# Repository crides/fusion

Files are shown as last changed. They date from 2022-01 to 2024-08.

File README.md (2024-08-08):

# Fusion

My travel board. Uses minimum spacing with choc mini (PG1232) and Cirque touchpad. It's meant to be folded for easy packing for traveling/going to classes. It's called fusion because the halves are now "fused" together (all my previous boards have been split).

The following picture shows how it's originally assembled:

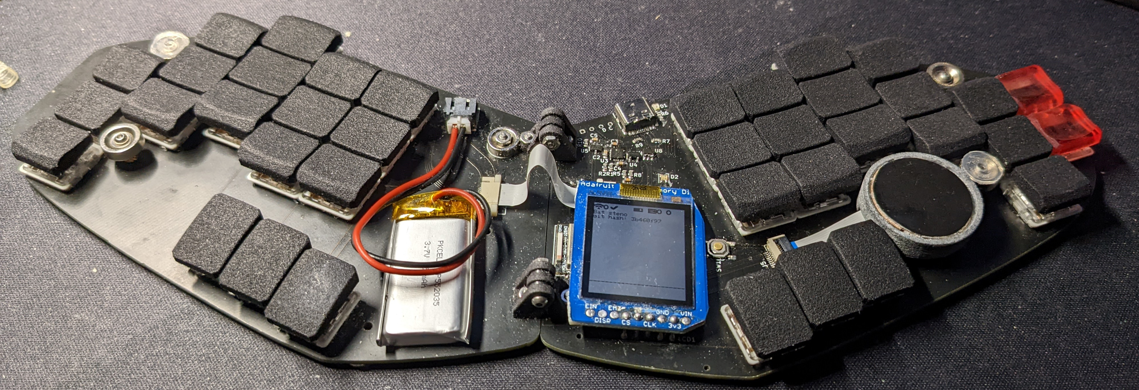
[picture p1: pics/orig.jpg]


You can find the caps [here](https://github.com/crides/sqdg). They are printed with the MJF Nylon process at JLCPCB.

The 2 extra pinky keys on the right side are different because I forgot about them when designing and printing the keycaps. Those keys are for steno, and like [the `fissure`](https://github.com/crides/fissure/) this includes [embedded stenograpy](https://github.com/crides/steno/).

The keymap is basically the same as [on the fissure](https://github.com/crides/fissure/?tab=readme-ov-file#latest-keymap) with a little difference in how the gaming and alternative layout layers are toggled.

One extra small feature it has is a PWM controlled RGB LED, which I use to display [LED widgets](https://github.com/zmkfirmware/zmk/issues/1003) on.

You can find a recent-ish configuration for this board [here](https://github.com/crides/zmk/tree/fusion-led-c-config/).

With the 350mAh battery on the board, this lasted me ~5 months of usage (it could've been even longer, the battery started out not on full charge (~3.8V)).

The board measures 148 x 79.5 x 21mm when it's folded (23mm thick if you include the bumpons, and 133mm long if the last 2 keys are cut off, like in the current state (see the bottom of this page)), which fits into a small bag. I carry this with my Pixel 5a in my big sweatpants pocket for quite a while. I would just go to places, take out the keeb and my phone, unfold it and work with Termux.

All parts are generated from Python, some using [solidff](https://github.com/crides/solidff), some using [CadQuery](https://github.com/CadQuery/cadquery/), depending on when the part was designed. The only parts actually used are `hinge1`, `hinge2` and `touchpad-holder`.

Includes JLCPCB BOM ([`bom.csv`](bom.csv)) and POS ([`pos.csv`](pos.csv)) files for PCBA.

---

Here's the board after almost 11 months of usage (right before 2023):

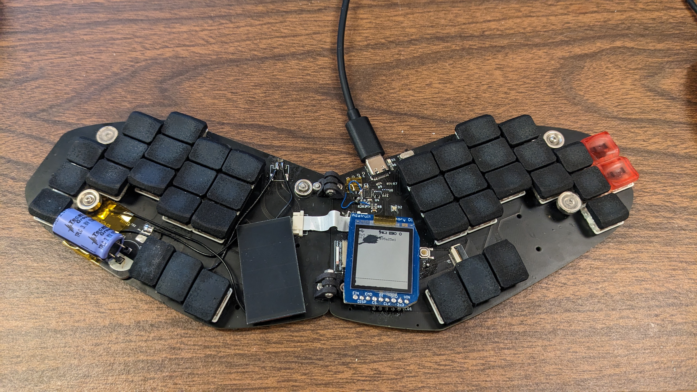
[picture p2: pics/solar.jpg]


Main differences:
- The trackpad is in a really weird spot. I knew this in the design phase, but didn't have much idea of how to fix it. So it's taken out. 
- A solar charging circuit with a Li-ion supercapacitor is added, replacing the battery and its charging circuit. The current supercap is 150F (!), which is equivalent to about 40mAh. This was to be done on another version of the board, but a small test circuit was fabbed instead, and that was used here with a fair amount of bodging. Now I can say the fusion board is (well can be) powered by fusion! (a.k.a. solar powered)
- There's a crack on the screen. The adhesive I used didn't cover the whole screen area, and once I pressed on the top left corner too hard, where the adhesive also didn't cover and left some empty space, and it cracked :(.

---

Here it is after 1 year:

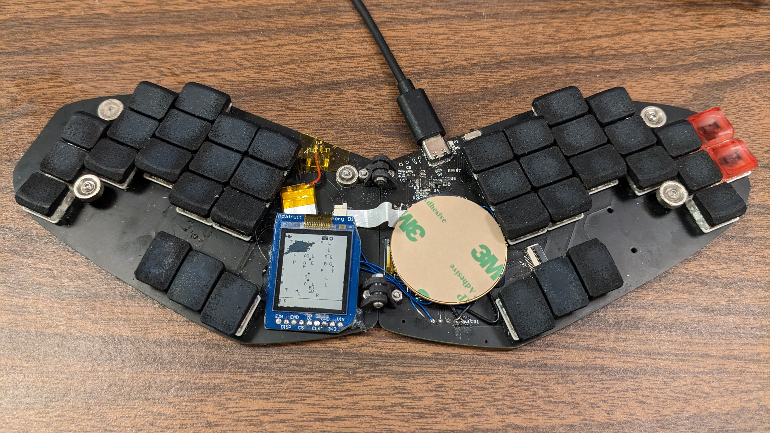
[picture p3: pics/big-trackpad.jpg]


Somehow the supercap doesn't seem to do well with the cold, so I swapped to the old small battery. Tried out a larger Cirque touchpad, by basically shifting the screen to the left side though a bunch of wires.

---

Here's what it looks like after 16 months:

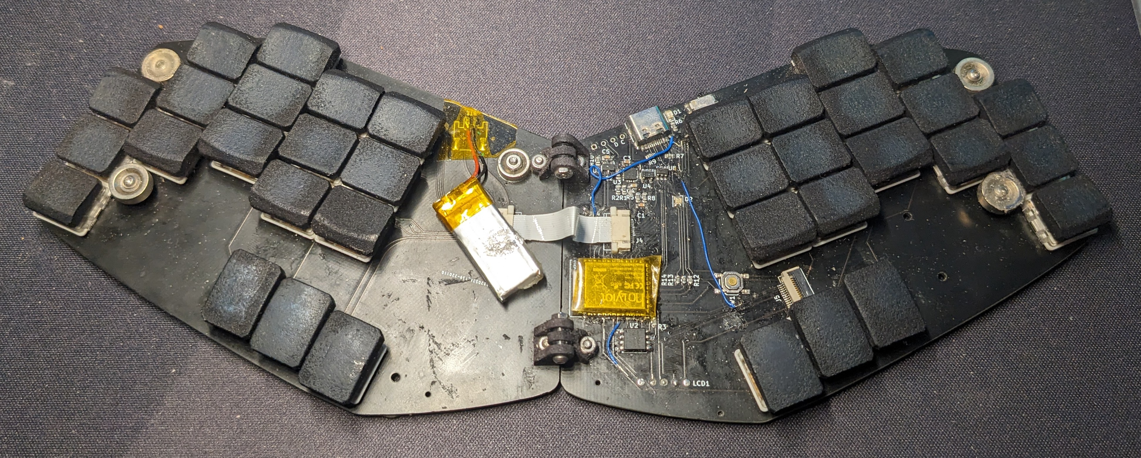
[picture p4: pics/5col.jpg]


The screen's completely broken, with the ribbon cable half "cut" (no idea how that happened). The trackpad location is better, but still pretty useless for my use cases (I use it 95% on top of my laptop keyboard most of the time, and the touchpad is right there, with more ready-to-be-used gestures. So touchpads and solar panels are gone. Nothing interesting to see here...

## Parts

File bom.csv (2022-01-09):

Comment | Designator | Footprint | LCSC
Battery_Cell | BT1 | Connector_JST:JST_PH_S2B-PH-SM4-TB_1x02-1MP_P2.00mm_Horizontal
10nF | C1 | Capacitor_SMD:C_0603_1608Metric
4.7uF | C2,C3,C4 | Capacitor_SMD:C_0603_1608Metric
0.1uF | C5 | Capacitor_SMD:C_0603_1608Metric | C14663
RED | D1 | LED_SMD:LED_0805_2012Metric
LED_RABG | D2 | LED_SMD:LED_ASMB-KTF0-0A306 | C375569
bat-shell | H20 | fusion:bat-shell-small
USB_C_Receptacle_USB2.0 | J2 | Connector_USB:USB_C_Receptacle_HRO_TYPE-C-31-M-12 | C165948
cirque-trackpad | J5 | Connector_FFC-FPC:Hirose_FH12-12S-0.5SH_1x12-1MP_P0.50mm_Horizontal
diode-choc | K1,K6,K11,K19,K24,K29,K34,K35 | pg1232:pg1232-DSSN | C64898
diode-choc | K2,K5,K7,K10,K12,K15,K22,K27,K32 | pg1232:pg1232-DSSR | C64898
diode-choc | K3,K8,K13,K16,K17,K18,K21,K26,K31,K36,K37,K38 | pg1232:pg1232-DSS | C64898
diode-choc | K4,K9,K14,K20,K23,K25,K28,K30,K33 | pg1232:pg1232-DSSL | C64898
adafruit-sharp-memory-display-no-useless | LCD1 | display:adafruit-sharp-memory-display-1.3in-no-mounting-no-useless
10k | R1,R2 | Resistor_SMD:R_0603_1608Metric
100k | R3,R10 | Resistor_SMD:R_0603_1608Metric
5.1M | R5,R8 | Resistor_SMD:R_0603_1608Metric | C13320
1k | R6,R14 | Resistor_SMD:R_0603_1608Metric
5.1k | R7,R9 | Resistor_SMD:R_0603_1608Metric
1.2k | R12 | Resistor_SMD:R_0603_1608Metric
1.5k | R13 | Resistor_SMD:R_0603_1608Metric
SW_Push | SW1 | Button_Switch_SMD:SW_SPST_TL3342 | C318884
SW_SPDT | SW2 | Button_Switch_SMD:SW_SPDT_PCM12 | C431541
holyiot-18010-no-underside | U1 | mcu:holyiot-18010-no-underside
MT25QL128ABA1ESE | U2 | Package_SO:SOIC-8_5.23x5.23mm_P1.27mm | C97521
BQ24075 | U3 | Package_DFN_QFN:VQFN-16-1EP_3x3mm_P0.5mm_EP1.68x1.68mm_ThermalVias
XC6206B331MR | U4 | Package_TO_SOT_SMD:SOT-23-5 | C155728
LN4913 | U5 | Package_TO_SOT_SMD:SOT-23 | C236384
SRV05-4 | U8 | Package_TO_SOT_SMD:SOT-23-6

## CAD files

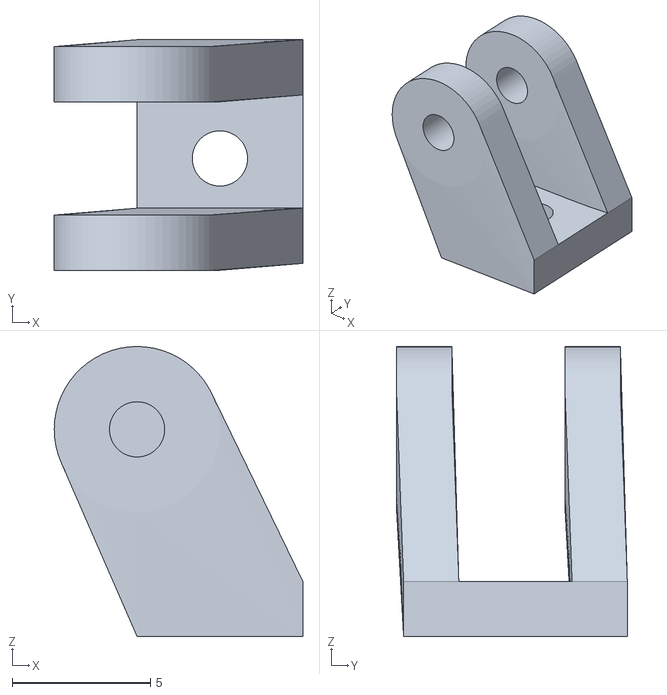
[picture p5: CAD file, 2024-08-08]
hinge2.stl
9.00 x 8.35 x 10.5

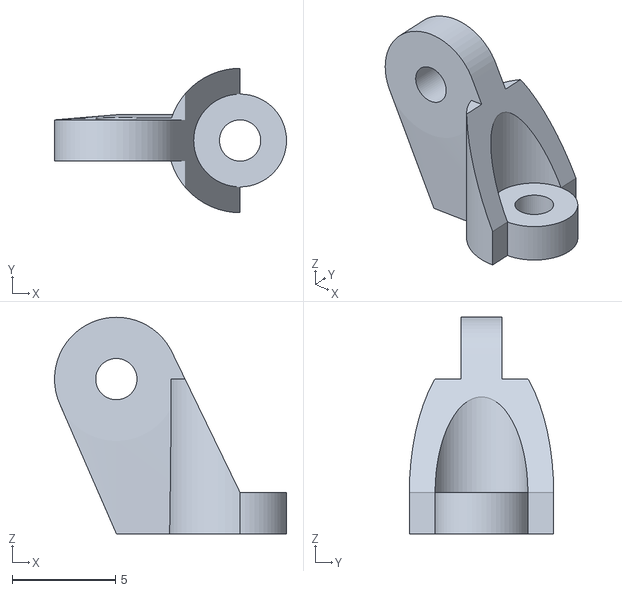
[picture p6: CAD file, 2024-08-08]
hinge1.stl
11.2 x 7.00 x 10.5

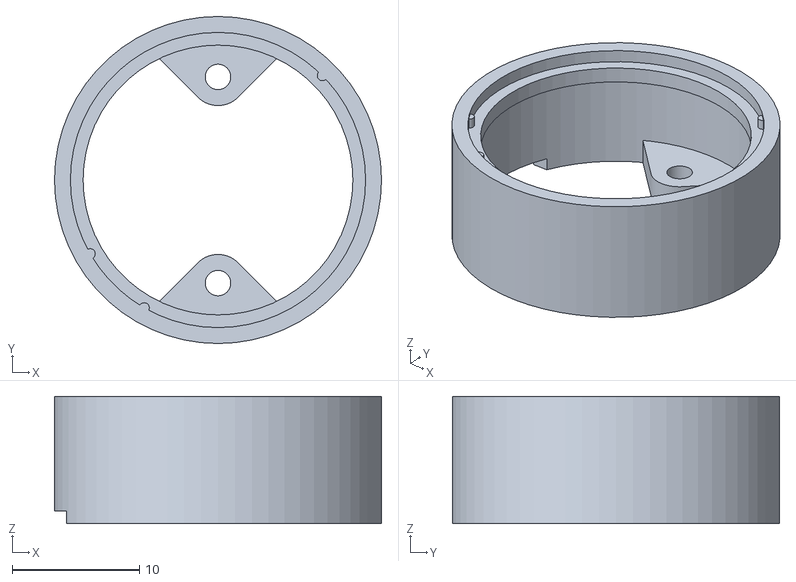
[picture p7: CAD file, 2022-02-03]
touchpad-holder.stl
25.7 x 25.7 x 10.0

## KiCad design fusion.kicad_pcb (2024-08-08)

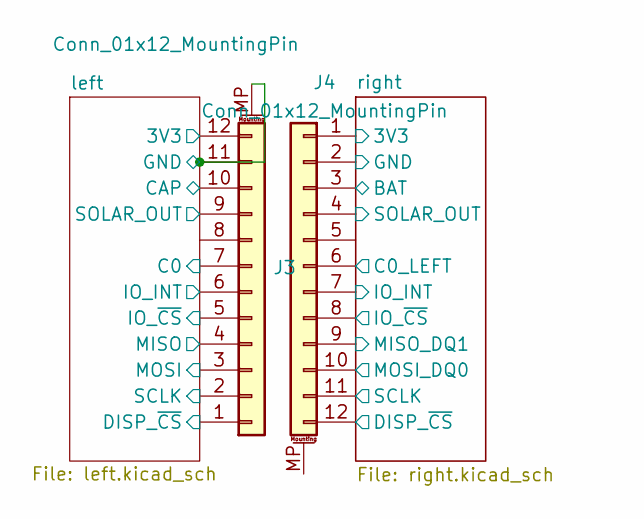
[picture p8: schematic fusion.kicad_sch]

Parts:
J3, J4: Conn_01x12_MountingPin; Hirose_FH12-12S-0.5SH_1x12-1MP_P0.50mm_Horizontal

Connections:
/left/3V3: J3.12; also elsewhere on the board
/left/C0: J3.7; also elsewhere on the board
/left/CAP: J3.10; also elsewhere on the board
/left/DISP_~CS: J3.1; also elsewhere on the board
/left/GND: J3.11, J3.MP (MountPin); also elsewhere on the board
/left/IO_INT: J3.6; also elsewhere on the board
/left/IO_~CS: J3.5; also elsewhere on the board
/left/MISO: J3.4; also elsewhere on the board
/left/MOSI: J3.3; also elsewhere on the board
/left/SCLK: J3.2; also elsewhere on the board
/left/SOLAR_OUT: J3.9; also elsewhere on the board
/right/3V3_nRF: J4.1; also elsewhere on the board
/right/BAT: J4.3; also elsewhere on the board
/right/C0_LEFT: J4.6; also elsewhere on the board
/right/DISP_~CS: J4.12; also elsewhere on the board
/right/IO_INT: J4.7; also elsewhere on the board
/right/IO_~CS: J4.8; also elsewhere on the board
/right/MISO_DQ1: J4.9; also elsewhere on the board
/right/MOSI_DQ0: J4.10; also elsewhere on the board
/right/SCLK: J4.11; also elsewhere on the board
/right/SOLAR_OUT: J4.4; also elsewhere on the board
GND: J4.2; also elsewhere on the board

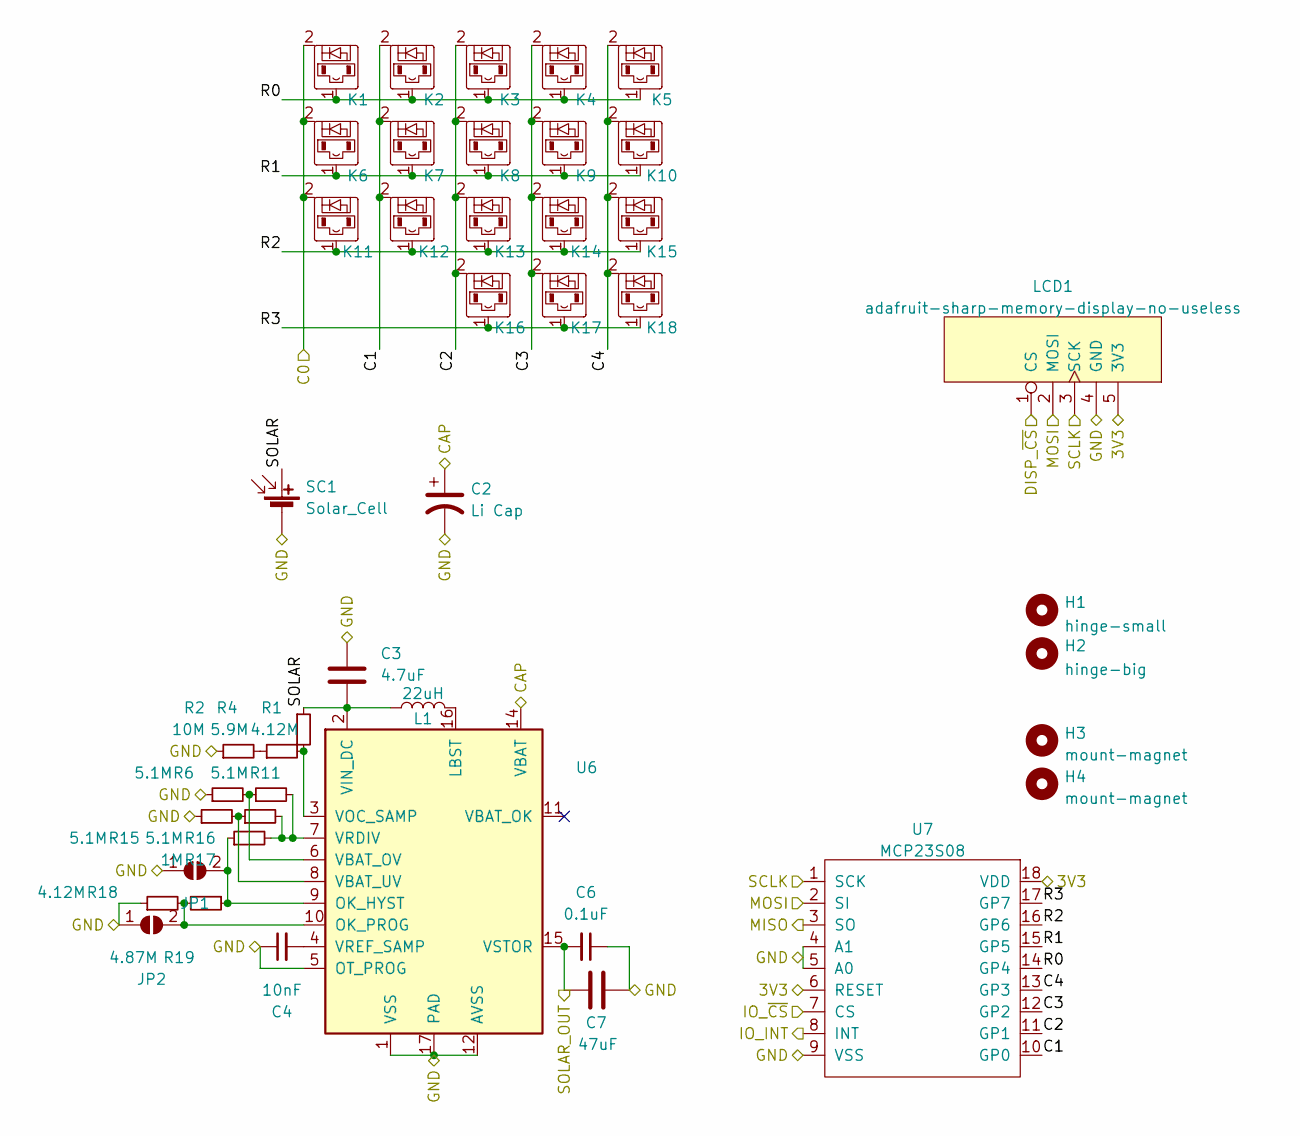
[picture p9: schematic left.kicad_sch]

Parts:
C2: Li Cap; CP_Radial_D13.0mm_P5.00mm
C3: 4.7uF; C_0603_1608Metric
C4: 10nF; C_0603_1608Metric
C6: 0.1uF; C_0603_1608Metric
C7: 47uF; C_0805_2012Metric
H1: hinge-small; hinge1
H2: hinge-big; hinge2
H3, H4: mount-magnet; m2-heat-insert-pad
JP1: SolderJumper-2_P1.3mm_Open_RoundedPad1.0x1.5mm
JP2: SolderJumper_2_Open; SolderJumper-2_P1.3mm_Open_RoundedPad1.0x1.5mm
K1, K5, K6, K10, K11, K15: diode-choc; pg1232-DCN
K2, K7, K12: diode-choc; pg1232-DCR
K3, K8, K13, K16, K17, K18: diode-choc; pg1232-DC
K4, K9, K14: diode-choc; pg1232-DCL
L1: 22uH; L_Wuerth_WE-TPC-3816
LCD1: adafruit-sharp-memory-display-no-useless; adafruit-sharp-memory-display-1.3in-no-mounting-no-useless
R1, R18: 4.12M; R_0603_1608Metric
R2: 10M; R_0603_1608Metric
R4: 5.9M; R_0603_1608Metric
R6, R11, R15, R16: 5.1M; R_0603_1608Metric
R17: 1M; R_0603_1608Metric
R19: 4.87M; R_0603_1608Metric
SC1: Solar_Cell; KXOB25-05X3F
U6: QFN-16-1EP_3x3mm_P0.5mm_EP1.7x1.7mm
U7: MCP23S08; SOIC-18W_7.5x11.6mm_P1.27mm

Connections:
/left/3V3: LCD1.5 (3V3), U7.6 (RESET), U7.18 (VDD); also elsewhere on the board
/left/C0: K1.2, K6.2, K11.2; also elsewhere on the board
/left/C1: K2.2, K7.2, K12.2, U7.10 (GP0)
/left/C2: K3.2, K8.2, K13.2, K16.2, U7.11 (GP1)
/left/C3: K4.2, K9.2, K14.2, K17.2, U7.12 (GP2)
/left/C4: K5.2, K10.2, K15.2, K18.2, U7.13 (GP3)
/left/CAP: C2.1, U6.14 (VBAT); also elsewhere on the board
/left/DISP_~CS: LCD1.1 (CS); also elsewhere on the board
/left/GND: C2.2, C3.1, C4.1, C6.1, C7.2, JP1.1 (A), JP2.1 (A), LCD1.4 (GND), R2.1, R6.1, R15.1, R18.1, SC1.2 (-), U6.1 (VSS), U6.5 (OT_PROG), U6.12 (AVSS), U6.13 (VSS), U6.17 (PAD), U7.4 (A1), U7.5 (A0), U7.9 (VSS); also elsewhere on the board
/left/IO_INT: U7.8 (INT); also elsewhere on the board
/left/IO_~CS: U7.7 (CS); also elsewhere on the board
/left/MISO: U7.3 (SO); also elsewhere on the board
/left/MOSI: LCD1.2 (MOSI), U7.2 (SI); also elsewhere on the board
/left/R0: K1.1, K2.1, K3.1, K4.1, K5.1, U7.14 (GP4)
/left/R1: K6.1, K7.1, K8.1, K9.1, K10.1, U7.15 (GP5)
/left/R2: K11.1, K12.1, K13.1, K14.1, K15.1, U7.16 (GP6)
/left/R3: K16.1, K17.1, K18.1, U7.17 (GP7)
/left/SCLK: LCD1.3 (SCK), U7.1 (SCK); also elsewhere on the board
/left/SOLAR: C3.2, L1.1, R1.1, SC1.1 (+), U6.2 (VIN_DC)
/left/SOLAR_OUT: C6.2, C7.1, U6.15 (VSTOR); also elsewhere on the board
unnamed: C4.2, U6.4 (VREF_SAMP)
unnamed: JP1.2 (B), R17.1, R19.1, U6.9 (OK_HYST)
unnamed: JP2.2 (B), R18.2, R19.2, U6.10 (OK_PROG)
unnamed: L1.2, U6.16 (LBST)
unnamed: R1.2, R4.2, U6.3 (VOC_SAMP)
unnamed: R2.2, R4.1
unnamed: R6.2, R11.1, U6.6 (VBAT_OV)
unnamed: R11.2, R16.2, R17.2, U6.7 (VRDIV)
unnamed: R15.2, R16.1, U6.8 (VBAT_UV)

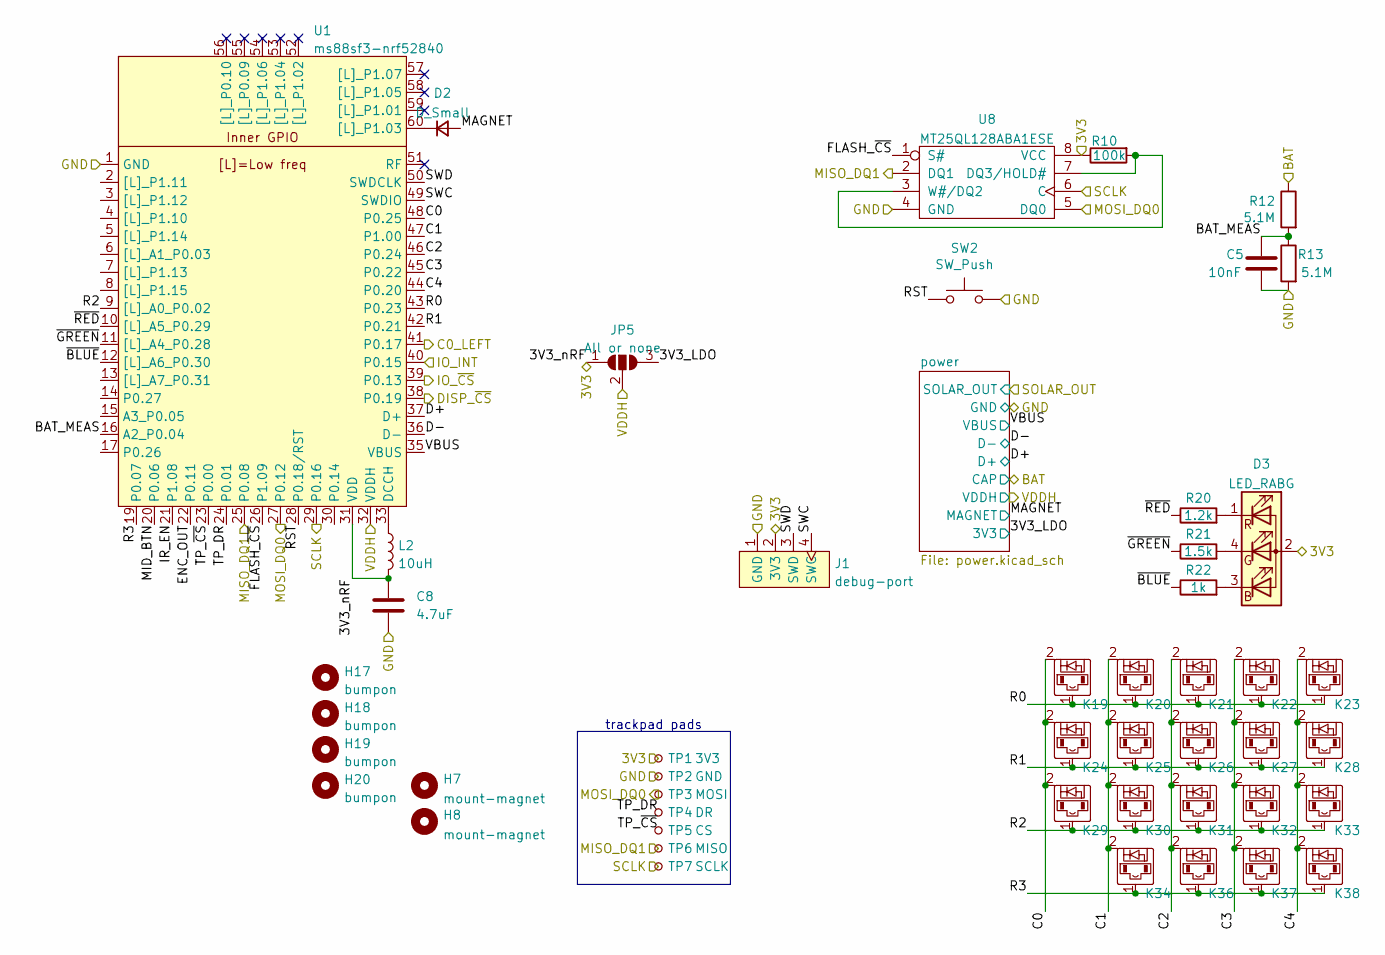
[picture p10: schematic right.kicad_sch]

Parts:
C5: 10nF; C_0603_1608Metric
C8: 4.7uF; C_0603_1608Metric
D2: D_Small; D_SOD-123
D3: LED_RABG; LED_ASMB-KTF0-0A306
H7, H8: mount-magnet; m2-heat-insert-pad
H17, H18, H19, H20: bumpon; bumpon-sunk-hole
J1: debug-port; debug-port-single-side
JP5: All or none; SolderJumper-3_P1.3mm_Open_RoundedPad1.0x1.5mm
K19, K23, K24, K28, K29, K33: diode-choc; pg1232-DCN
K20, K25, K30: diode-choc; pg1232-DCL
K21, K26, K31, K36, K37, K38: diode-choc; pg1232-DC
K22, K27, K32: diode-choc; pg1232-DCR
K34: diode-choc; pg1232-DSS
L2: 10uH; L_0603_1608Metric
R10: 100k; R_0603_1608Metric
R12, R13: 5.1M; R_0603_1608Metric
R20: 1.2k; R_0603_1608Metric
R21: 1.5k; R_0603_1608Metric
R22: 1k; R_0603_1608Metric
SW2: SW_Push; SW_SPST_TL3342
TP1: 3V3; TestPoint_THTPad_D1.0mm_Drill0.5mm
TP2: GND; TestPoint_THTPad_D1.0mm_Drill0.5mm
TP3: MOSI; TestPoint_THTPad_D1.0mm_Drill0.5mm
TP4: DR; TestPoint_THTPad_D1.0mm_Drill0.5mm
TP5: CS; TestPoint_THTPad_D1.0mm_Drill0.5mm
TP6: MISO; TestPoint_THTPad_D1.0mm_Drill0.5mm
TP7: SCLK; TestPoint_THTPad_D1.0mm_Drill0.5mm
U1: ms88sf3-nrf52840; ms88sf3
U8: MT25QL128ABA1ESE; SOIC-8_5.23x5.23mm_P1.27mm

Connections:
/right/3V3_LDO: JP5.3 (B); also elsewhere on the board
/right/3V3_nRF: C8.1, D3.2 (A), J1.2 (3V3), JP5.1 (A), L2.2, R10.1, TP1.1, U1.31 (VDD), U8.8 (VCC); also elsewhere on the board
/right/BAT: R12.1; also elsewhere on the board
/right/BAT_MEAS: C5.1, R12.2, R13.1, U1.16 (A2_P0.04)
/right/C0: K19.2, K24.2, K29.2, U1.48 (P0.25)
/right/C0_LEFT: U1.41 (P0.17); also elsewhere on the board
/right/C1: K20.2, K25.2, K30.2, K34.2, U1.47 (P1.00)
/right/C2: K21.2, K26.2, K31.2, K36.2, U1.46 (P0.24)
/right/C3: K22.2, K27.2, K32.2, K37.2, U1.45 (P0.22)
/right/C4: K23.2, K28.2, K33.2, K38.2, U1.44 (P0.20)
/right/D+: U1.37 (D+); also elsewhere on the board
/right/D-: U1.36 (D-); also elsewhere on the board
/right/DISP_~CS: U1.38 (P0.19); also elsewhere on the board
/right/ENC_OUT: U1.22 (P0.11); also elsewhere on the board
/right/FLASH_~CS: U1.26 (P1.09), U8.1 (S#)
/right/IO_INT: U1.40 (P0.15); also elsewhere on the board
/right/IO_~CS: U1.39 (P0.13); also elsewhere on the board
/right/IR_EN: U1.21 (P1.08); also elsewhere on the board
/right/MAGNET: D2.2 (A); also elsewhere on the board
/right/MID_BTN: U1.20 (P0.06); also elsewhere on the board
/right/MISO_DQ1: TP6.1, U1.25 (P0.08), U8.2 (DQ1); also elsewhere on the board
/right/MOSI_DQ0: TP3.1, U1.27 (P0.12), U8.5 (DQ0); also elsewhere on the board
/right/R0: K19.1, K20.1, K21.1, K22.1, K23.1, U1.43 (P0.23)
/right/R1: K24.1, K25.1, K26.1, K27.1, K28.1, U1.42 (P0.21)
/right/R2: K29.1, K30.1, K31.1, K32.1, K33.1, U1.9 ([L]_A0_P0.02)
/right/R3: K34.1, K36.1, K37.1, K38.1, U1.19 (P0.07)
/right/RST: SW2.1, U1.28 (P0.18/RST)
/right/SCLK: TP7.1, U1.29 (P0.16), U8.6 (C); also elsewhere on the board
/right/SWC: J1.4 (SWC), U1.49 (SWDIO)
/right/SWD: J1.3 (SWD), U1.50 (SWDCLK)
/right/TP_DR: TP4.1, U1.24 (P0.01)
/right/TP_~CS: TP5.1, U1.23 (P0.00)
/right/VBUS: U1.35 (VBUS); also elsewhere on the board
/right/VDDH: JP5.2 (C), U1.32 (VDDH); also elsewhere on the board
/right/~BLUE: R22.1, U1.12 ([L]_A6_P0.30)
/right/~GREEN: R21.1, U1.11 ([L]_A4_P0.28)
/right/~RED: R20.1, U1.10 ([L]_A5_P0.29)
GND: C5.2, C8.2, J1.1 (GND), R13.2, SW2.2, TP2.1, U1.1 (GND), U1.18 (GND), U1.34 (GND), U1.61 (GND), U1.62 (GND), U1.63 (GND), U1.64 (GND), U8.4 (GND); also elsewhere on the board
unnamed: D2.1 (K), U1.60 ([L]_P1.03)
unnamed: D3.1 (RK), R20.2
unnamed: D3.3 (BK), R22.2
unnamed: D3.4 (GK), R21.2
unnamed: L2.1, U1.33 (DCCH)
unnamed: R10.2, U8.3 (W#/DQ2), U8.7 (DQ3/HOLD#)

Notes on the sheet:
trackpad pads

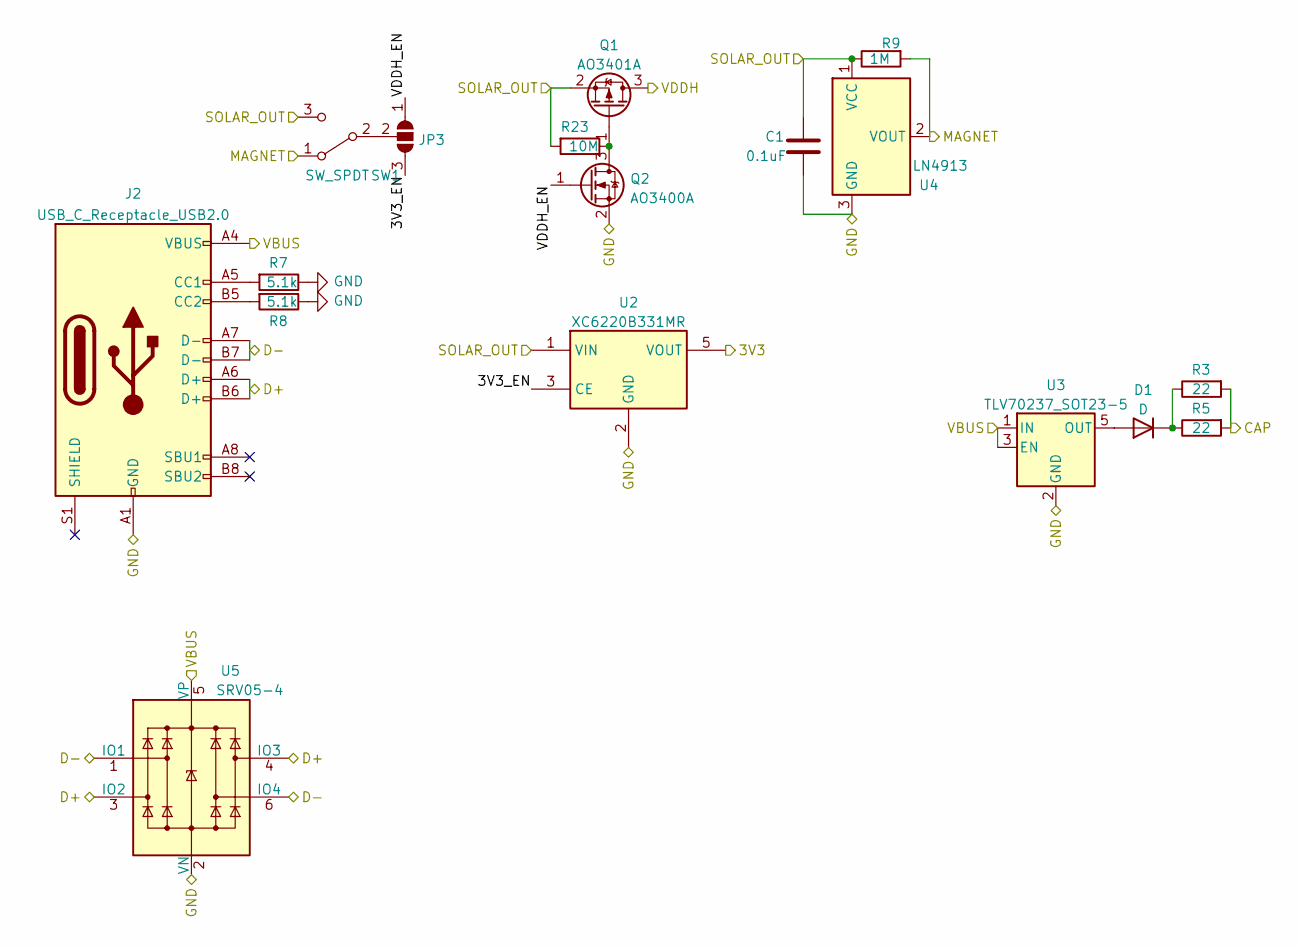
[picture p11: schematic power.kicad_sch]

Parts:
C1: 0.1uF; C_0603_1608Metric
D1: D; D_SOD-123
J2: USB_C_Receptacle_USB2.0; USB_C_Receptacle_HRO_TYPE-C-31-M-12
JP3: SolderJumper_3_Open; SolderJumper-3_P1.3mm_Open_RoundedPad1.0x1.5mm
Q1: AO3401A; SOT-23
Q2: AO3400A; SOT-23
R3, R5: 22; R_0603_1608Metric
R7, R8: 5.1k; R_0603_1608Metric
R9: 1M; R_0603_1608Metric
R23: 10M; R_0603_1608Metric
SW1: SW_SPDT; SW_SPDT_PCM12
U2: XC6220B331MR; SOT-23-5
U3: TLV70237_SOT23-5; SOT-23-5
U4: LN4913; SOT-23
U5: SRV05-4; SOT-23-6

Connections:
/right/3V3_LDO: U2.5 (VOUT); also elsewhere on the board
/right/BAT: R3.2, R5.2; also elsewhere on the board
/right/D+: J2.A6 (D+), J2.B6 (D+), U5.3 (IO2), U5.4 (IO3); also elsewhere on the board
/right/D-: J2.A7 (D-), J2.B7 (D-), U5.1 (IO1), U5.6 (IO4); also elsewhere on the board
/right/MAGNET: R9.2, SW1.1 (A), U4.2 (VOUT); also elsewhere on the board
/right/SOLAR_OUT: C1.1, Q1.2 (S), R9.1, R23.2, SW1.3 (C), U2.1 (VIN), U4.1 (VCC); also elsewhere on the board
/right/VBUS: J2.A4 (VBUS), J2.A9 (VBUS), J2.B4 (VBUS), J2.B9 (VBUS), U3.1 (IN), U3.3 (EN), U5.5 (VP); also elsewhere on the board
/right/VDDH: Q1.3 (D); also elsewhere on the board
/right/power/3V3_EN: JP3.3 (B), U2.3 (CE)
/right/power/VDDH_EN: JP3.1 (A), Q2.1 (G)
GND: C1.2, J2.A1 (GND), J2.A12 (GND), J2.B1 (GND), J2.B12 (GND), Q2.2 (S), R7.1, R8.1, U2.2 (GND), U3.2 (GND), U4.3 (GND), U5.2 (VN); also elsewhere on the board
unnamed: D1.1 (K), R3.1, R5.1
unnamed: D1.2 (A), U3.5 (OUT)
unnamed: J2.A5 (CC1), R7.2
unnamed: J2.B5 (CC2), R8.2
unnamed: JP3.2 (C), SW1.2 (B)
unnamed: Q1.1 (G), Q2.3 (D), R23.1

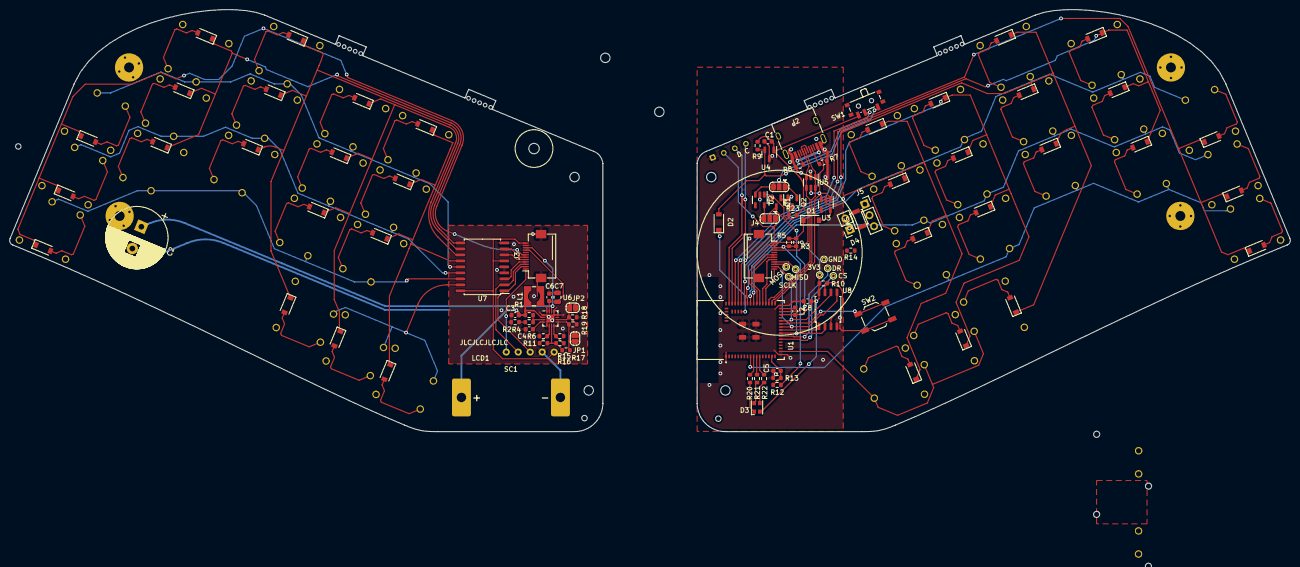
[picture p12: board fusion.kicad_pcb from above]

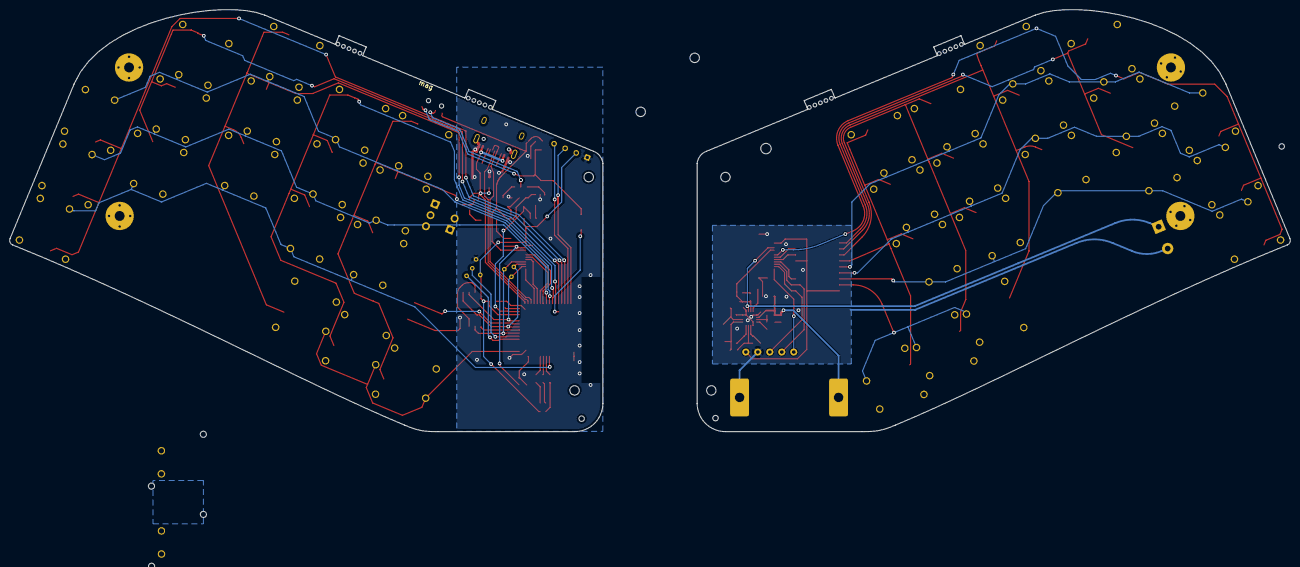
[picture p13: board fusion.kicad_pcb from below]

Board: 2 copper layers, 271.7 x 89.5 mm, 117 parts (2 on the bottom side), 83 nets.

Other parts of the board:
D4: LED; PinSocket_1x02_P2.54mm_Vertical
H5: hinge-big; hinge2
H6: hinge-small; hinge1
H9, H10, H11, H12: mouse-bite; breakaway-mousebites
J5: Conn_01x03_Female; PinSocket_1x03_P2.54mm_Vertical
P1: touchpad-holder
R14: 1k; R_0603_1608Metric
SW3: SW_Push; SW_SPST_B3U-1000P

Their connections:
/right/3V3_nRF: D4.2 (A), J5.2; also elsewhere on the board
/right/ENC_OUT: J5.1; also elsewhere on the board
/right/IR_EN: R14.2; also elsewhere on the board
/right/MID_BTN: SW3.2; also elsewhere on the board
GND: J5.3, SW3.1; also elsewhere on the board
unnamed: D4.1 (K), R14.1

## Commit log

2021-07-31 before hinges
    [fusion.kicad_pcb, fusion.kicad_sch]
2021-08-01 fpc and hinges
    [fusion.kicad_pcb, fusion.kicad_sch]
2021-08-16 use narrower pinky spacing
    [fusion.kicad_pcb, fusion.kicad_sch, left.kicad_sch]
2021-10-03 Hydrogen.PCB
    - add Adafruit CAD files for Sharp display
    - convert to all 3D printed mechanical parts
    - update part dimensions to lowest estimate
    [fusion-B_Cu.gbr, fusion-B_Mask.gbr, fusion-B_Silkscreen.gbr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]
2021-10-17 fix gerber issue
    This is just to generate a set of Gerbers so that people can print (if
    anyone does) the correct version easily. NOT TESTED
    [fusion-B_Cu.gbr, fusion-B_Mask.gbr, fusion-B_Silkscreen.gbr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]
2022-01-07 update models
    [bat-shell.stl, hinge1.stl, hinge2.stl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]
2022-01-07 update PCB
    use cirque trackpad, increase angle to 22.5
    [fusion.kicad_pcb, fusion.kicad_sch, left.kicad_sch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]
2022-01-07 fix(model): remove top bit from cylinder
    [hinge1.stl]
2022-01-08 add assembly tooling hole
    [bom.csv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]
2022-01-09 production version
    [bom.csv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]
2022-02-03 v2 parts
    [bat-shell.stl, hinge1.stl, hinge2.stl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]
2023-06-29 shell & adhesive cutting lines for the back
    [fusion.kicad_pcb, shell-left.stl, shell-right.stl]
2023-06-29 new version
    [fusion.kicad_pcb, fusion.kicad_sch]
2024-08-08 backup & remove useless things
    [bat-shell.stl, fusion.csv, fusion.kicad_pcb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]
2024-08-08 info for pocket keeb competition; fix hinge2
    [hinge1.stl, hinge2.stl]
